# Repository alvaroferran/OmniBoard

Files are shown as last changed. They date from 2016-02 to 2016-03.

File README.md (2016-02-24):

# OmniBoard

<p align="center">
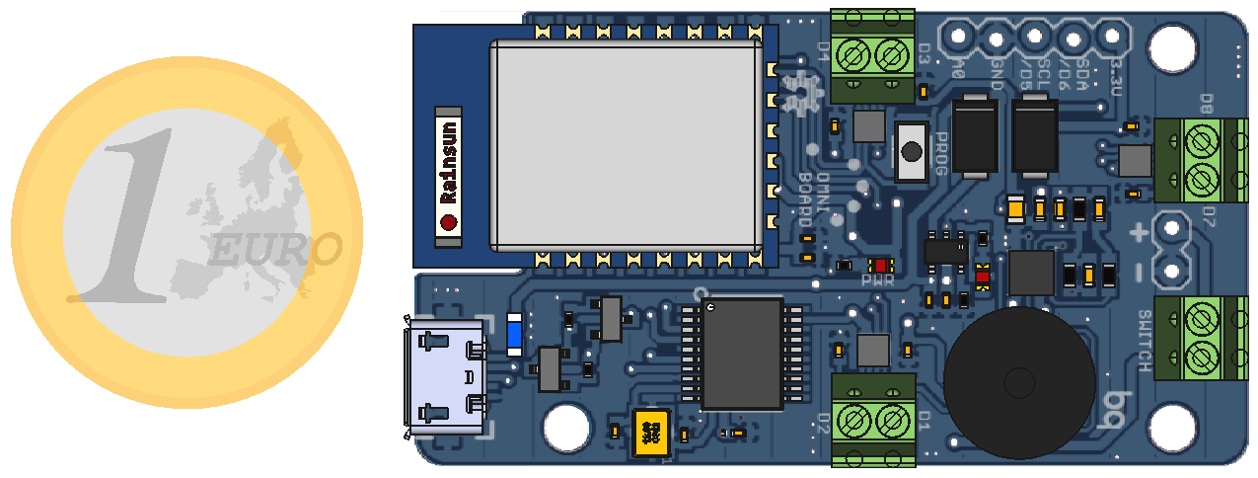
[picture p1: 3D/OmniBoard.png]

</p>

<br>

OmniBoard is a robotics controller board based on the ESP-12 module used to control up to three DC motors over wifi. It includes a 1S LiPo battery charger, a 3.5A boost circuit to ramp the voltage up to 5V for the motors and a hardware buzzer-based battery level indicator.

This board has been used to drive  <a href="https://github.com/bqlabs/miniloki">miniloki</a>:

<br>
This project is licensed under Creative Commons Attribution-ShareAlike 4.0 International (CC BY-SA 4.0)

<p align="center">

</p>

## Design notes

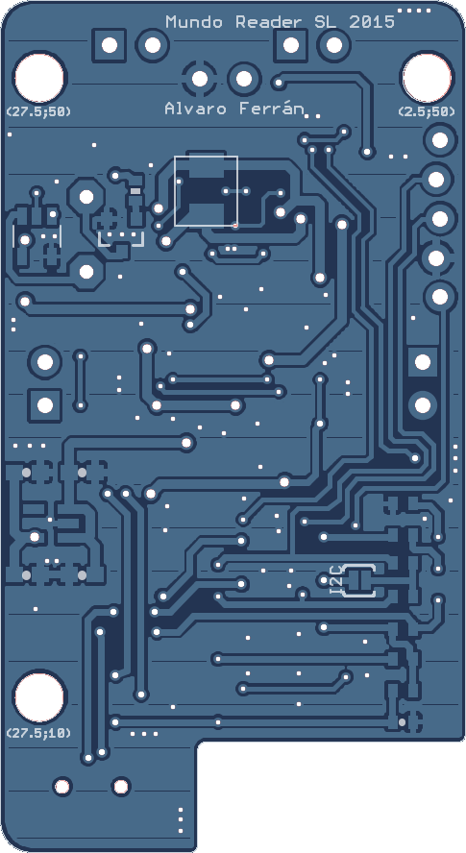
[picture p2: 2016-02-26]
Eagle/Silkscreen/Silkscreen2-Bottom.png

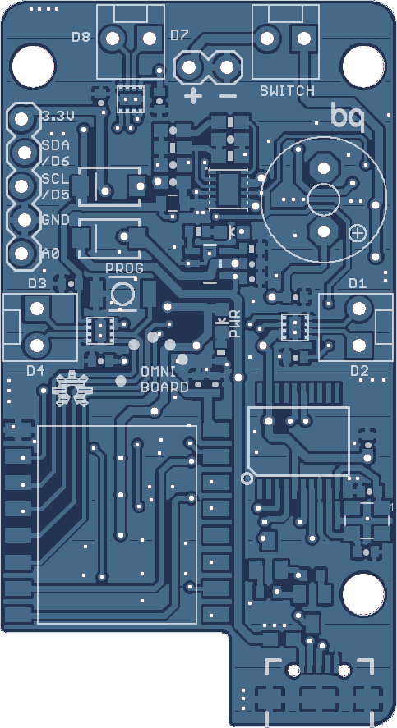
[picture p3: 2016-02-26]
Eagle/Silkscreen/Silkscreen1-Top.png

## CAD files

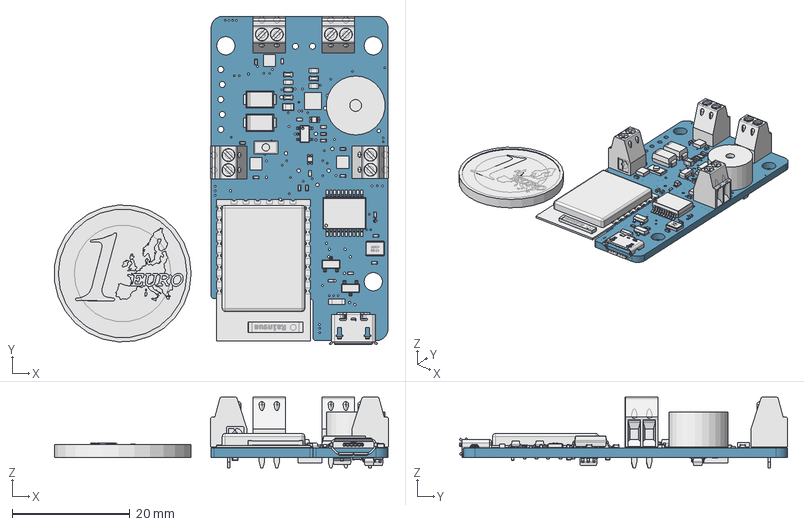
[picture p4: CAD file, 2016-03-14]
3D/OmniBoard.fcstd
56.6 x 55.7 x 12.0 mm
Board
R1
R2
R3
R4
R5
R9
R10
R11
R12
C2
C3
C5
C11
C10
C6
C18
C22
C19
C23
C17
C21
C14
C20
F1
JP2
Q1
U2
X1
IC1
U3
U4
C13
C15
C12
C16
C1
C4
C8
C7
JP1
JP3
JP4
JP7
U6
U7
U5
Q2
Q3
R14
R15
R13
R16
LED1
LED2
D2
D1
Q4
SG1
SW1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

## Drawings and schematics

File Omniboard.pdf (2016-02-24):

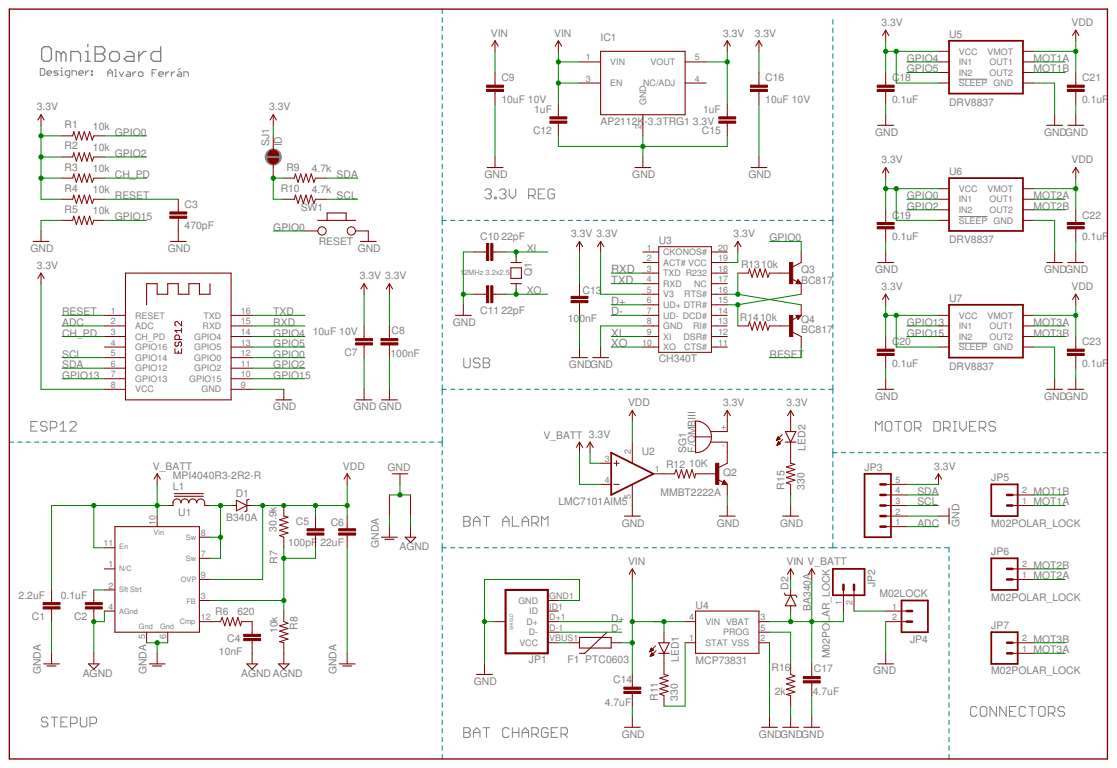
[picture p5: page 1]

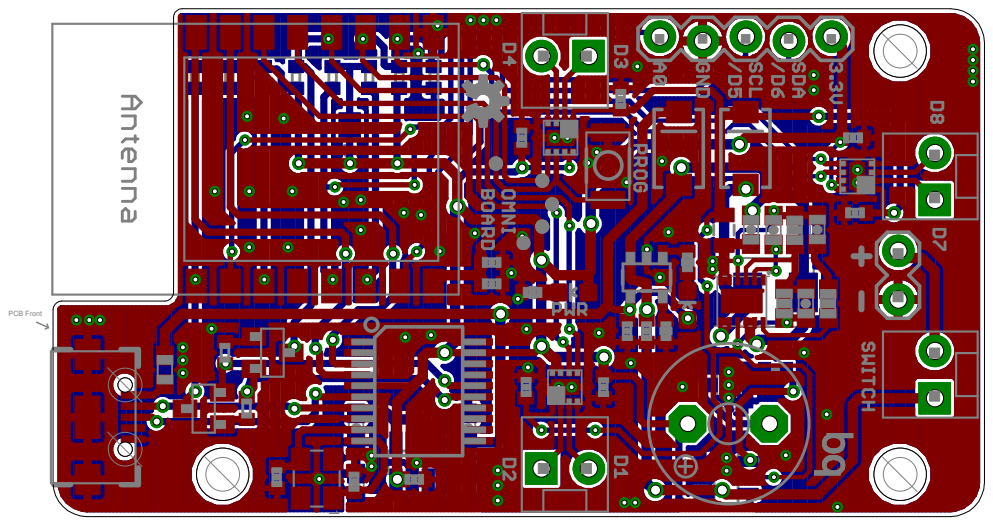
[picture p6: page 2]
PCB Front

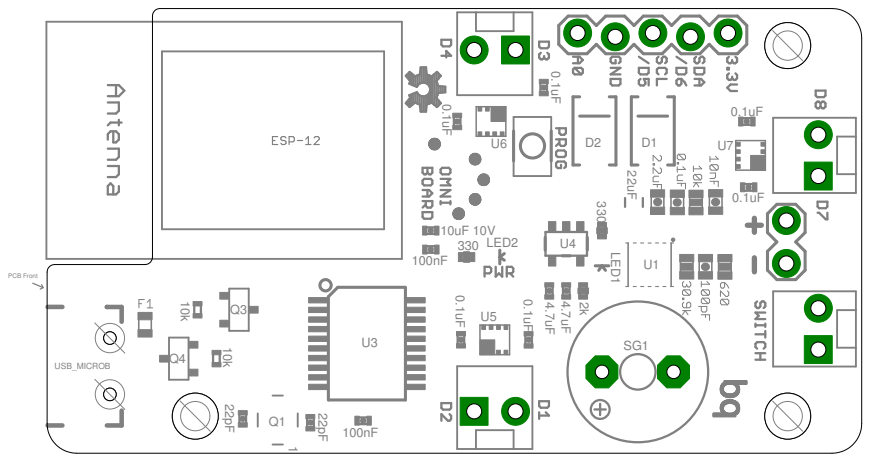
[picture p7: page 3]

U2

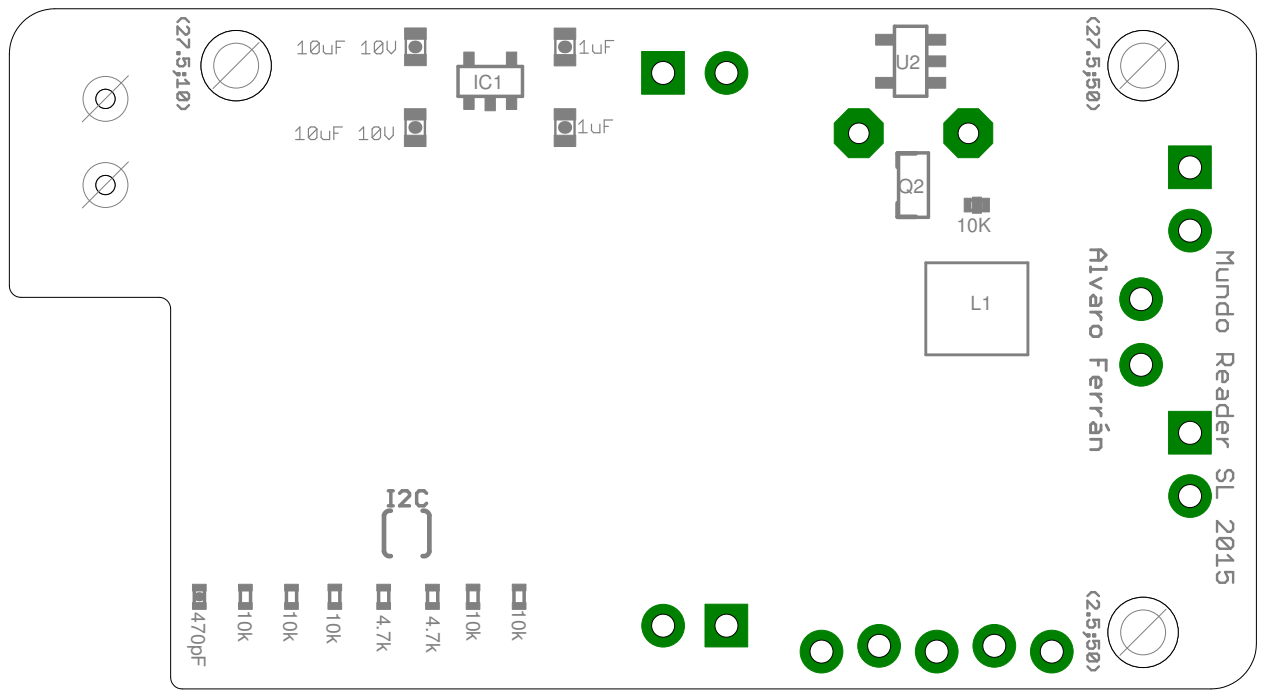
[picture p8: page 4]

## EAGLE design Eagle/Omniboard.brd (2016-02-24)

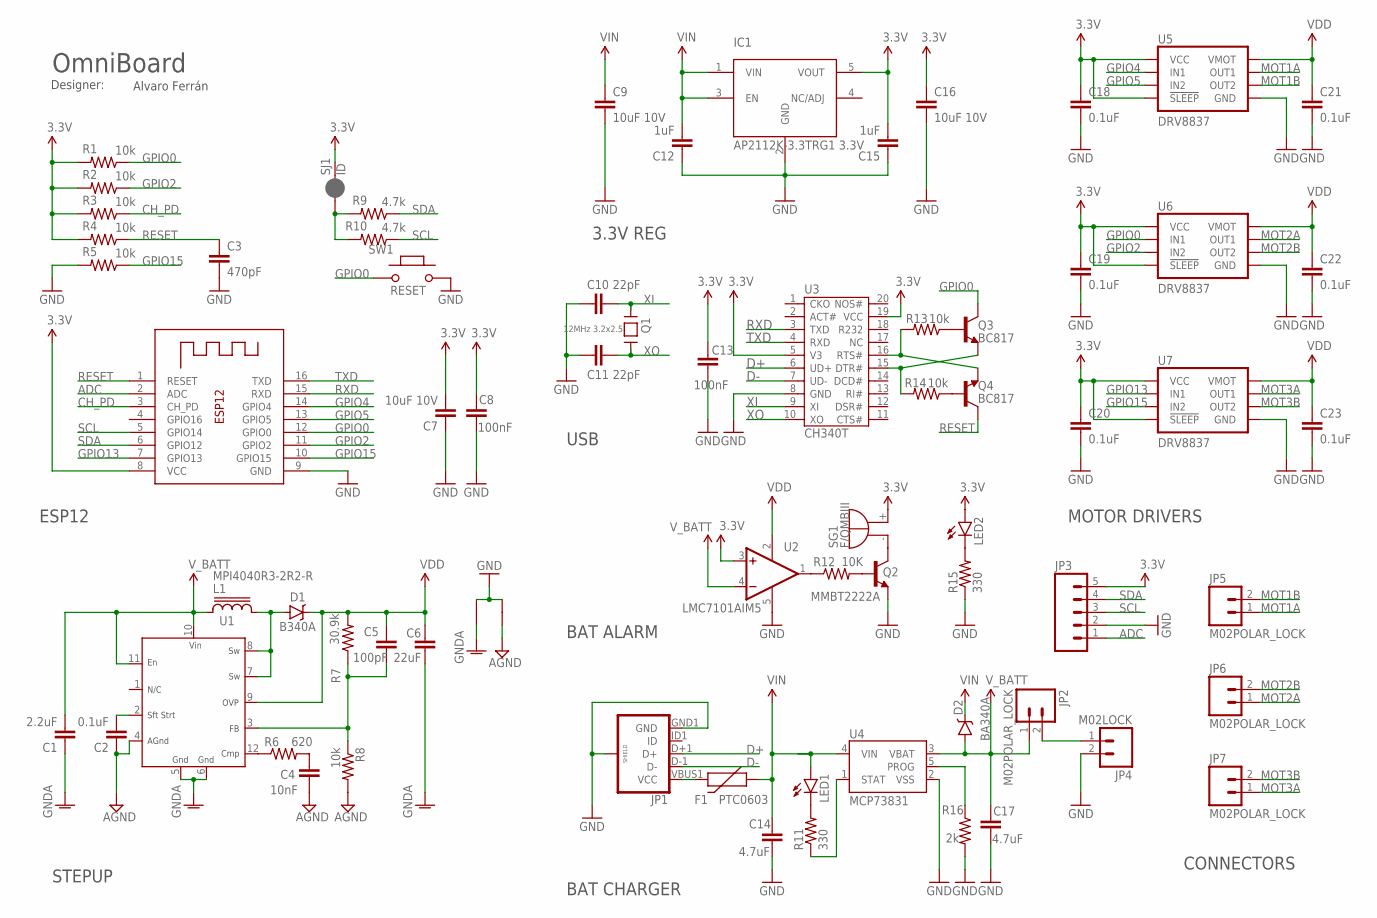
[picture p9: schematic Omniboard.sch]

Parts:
C1: 2.2uF; 0603-CAP
C2: 0.1uF; 0603-CAP
C3: 470pF; 0402-CAP
C4: 10nF; 0603-CAP
C5: 100pF; 0603-CAP
C6: 22uF; 0805
C7: 10uF 10V; 0402-CAP
C8, C13: 100nF; 0402-CAP
C9, C16: 10uF 10V; 0603-CAP
C10, C11: 22pF; 0402-CAP
C12, C15: 1uF; 0603-CAP
C14, C17: 4.7uF; 0402-CAP
C18, C19, C20, C21, C22, C23: 0.1uF; 0402-CAP
D1: B340A; SMA-DIODE
D2: BA340A; SMA-DIODE
F1: PTC0603; 0603
GND10, GND13: VIRTUAL_GND; STARGND
IC1: AP2112K-3.3TRG1 3.3V; SOT23-5
JP1: USB_MICROB; USB-B-MICRO-SMD_V03
JP2, JP5, JP6, JP7: M02POLAR_LOCK; MOLEX-1X2_LOCK
JP3: M05LOCK; 1X05_LOCK
JP4: M02LOCK; 1X02_LOCK
L1: MPI4040R3-2R2-R
LED1, LED2: LED0603; LED-0603
Q1: 12MHz 3.2x2.5; CRYSTAL_3.2X2.5
Q2: MMBT2222A; SOT23-3
Q3, Q4: BC817; SOT23-BEC
R1, R2, R3, R4, R5, R13, R14: 10k; R0402
R6: 620; 0603-RES
R7: 30.9k; 0603-RES
R8: 10k; 0603-RES
R9, R10: 4.7k; R0402
R11, R15: 330; 0402-RES
R12: 10K; 0402-RES
R16: 2k; 0402-RES
SG1: F/QMBIII
SJ1: ID; PAD-JUMPER-2-NC_BY_PASTE_YES_SILK
SW1: RESET; 157SW
U1: MIC2253; MLF12_3.0MM_X_3.0MM
U2: LMC7101AIM5; SOT23-5
U3: CH340T; SSOP20
U4: MCP73831; SOT23-5
U5, U6, U7: DRV8837; DSG
X1: ESP-12

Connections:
3.3V: C7.2, C8.1, C13.2, C15.2, C16.1, C18.1, C19.1, C20.1, IC1.5 (VOUT), JP3.5, LED2.A, R1.2, R2.2, R3.2, R4.2, SG1.+ (-), SJ1.2, U2.3 (+IN), U3.5 (V3), U3.19 (VCC), U5.7 (!SLEEP), U5.8 (VCC), U6.7 (!SLEEP), U6.8 (VCC), U7.7 (!SLEEP), U7.8 (VCC), X1.8 (VCC)
ADC: JP3.1, X1.2 (ADC)
AGND: C2.1, C4.1, GND13.P$1, R8.2, U1.4 (AGND)
CH_PD: R3.1, X1.3 (CH_PD)
D+: JP1.D+1 (D+), U3.6 (UD+)
D-: JP1.D-1 (D-), U3.7 (UD-)
GND: C3.2, C7.1, C8.2, C9.2, C10.1, C11.1, C12.1, C13.1, C14.2, C15.1, C16.2, C17.2, C18.2, C19.2, C20.2, C21.2, C22.2, C23.2, GND10.P$2, GND13.P$2, IC1.2 (GND), JP1.GND1 (GND), JP1.SHIELD1 (SHIELD), JP1.SHIELD2 (SHIELD), JP1.SHIELD3 (SHIELD), JP3.2, JP4.2, Q2.2 (E), R5.2, R15.1, R16.2, SW1.2, U2.5 (V-), U3.8 (GND), U4.2 (VSS), U5.4 (GND), U5.PAD (GND), U6.4 (GND), U6.PAD (GND), U7.4 (GND), U7.PAD (GND), X1.9 (GND)
GPIO0: Q3.C, R1.1, SW1.1, U6.6 (IN1), X1.12 (GPIO0)
GPIO2: R2.1, U6.5 (IN2), X1.11 (GPIO2)
GPIO4: U5.6 (IN1), X1.14 (GPIO4)
GPIO5: U5.5 (IN2), X1.13 (GPIO5)
GPIO13: U7.6 (IN1), X1.7 (GPIO13)
GPIO15: R5.1, U7.5 (IN2), X1.10 (GPIO15)
MOT1A: JP5.1, U5.2 (OUT1)
MOT1B: JP5.2, U5.3 (OUT2)
MOT2A: JP6.1, U6.2 (OUT1)
MOT2B: JP6.2, U6.3 (OUT2)
MOT3A: JP7.1, U7.2 (OUT1)
MOT3B: JP7.2, U7.3 (OUT2)
unnamed: R9.2, R10.2, SJ1.1
unnamed: Q3.E, R14.2, U3.15 (DTR#)
unnamed: C4.2, R6.2
unnamed: C2.2, U1.2 (SS)
unnamed: LED1.C, R11.2
unnamed: Q3.B, R13.1
unnamed: Q4.B, R14.1
unnamed: Q2.1 (B), R12.2
unnamed: Q2.3 (C), SG1.- (+)
unnamed: Q4.E, R13.2, U3.16 (RTS#)
unnamed: R16.1, U4.5 (PROG)
unnamed: D1.A, L1.P$2 (2), U1.7 (SW), U1.8 (SW)
unnamed: R11.1, U4.1 (STAT)
unnamed: F1.2, JP1.VBUS1 (VCC)
unnamed: LED2.C, R15.2
unnamed: R6.1, U1.12 (CMP)
unnamed: R12.1, U2.1 (OUT)
unnamed: C5.1, R7.1, R8.1, U1.3 (FB)
PGND: C1.1, C6.1, GND10.P$1, U1.5 (GND), U1.6 (GND)
RESET: C3.1, Q4.C, R4.1, X1.1 (RESET)
RXD: U3.3 (TXD), X1.15 (RXD)
SCL: JP3.3, R10.1, X1.5 (GPIO14)
SDA: JP3.4, R9.1, X1.6 (GPIO12)
TXD: U3.4 (RXD), X1.16 (TXD)
VBAT: JP2.2, JP4.1
VDD: C5.2, C6.2, C21.1, C22.1, C23.1, D1.C, R7.2, U1.9 (OVP), U2.2 (V+), U5.1 (VMOT), U6.1 (VMOT), U7.1 (VMOT)
VIN: C9.1, C12.2, C14.1, D2.C, F1.1, IC1.1 (VIN), IC1.3 (EN), LED1.A, U4.4 (VIN)
V_BATT: C1.2, C17.1, D2.A, JP2.1, L1.P$1 (1), U1.10 (VIN), U1.11 (EN), U2.4 (-IN), U4.3 (VBAT)
XI: C10.2, Q1.3, U3.9 (XI)
XO: C11.2, Q1.1, U3.10 (XO)

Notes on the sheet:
USB
OmniBoard
Designer:
Alvaro Ferrán
3.3V REG
ESP12
MOTOR DRIVERS
BAT ALARM
CONNECTORS
BAT CHARGER
STEPUP

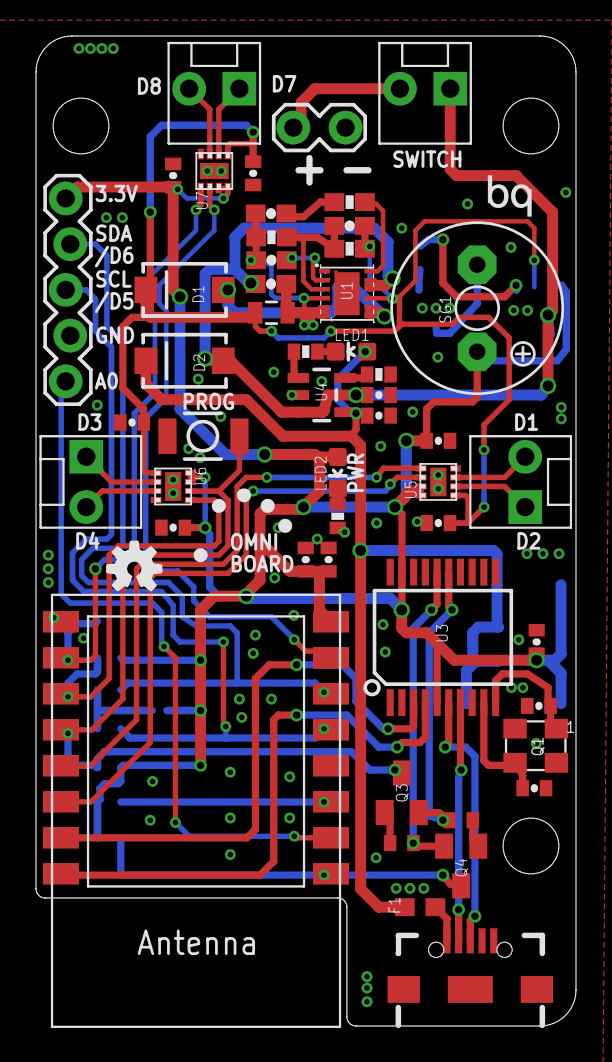
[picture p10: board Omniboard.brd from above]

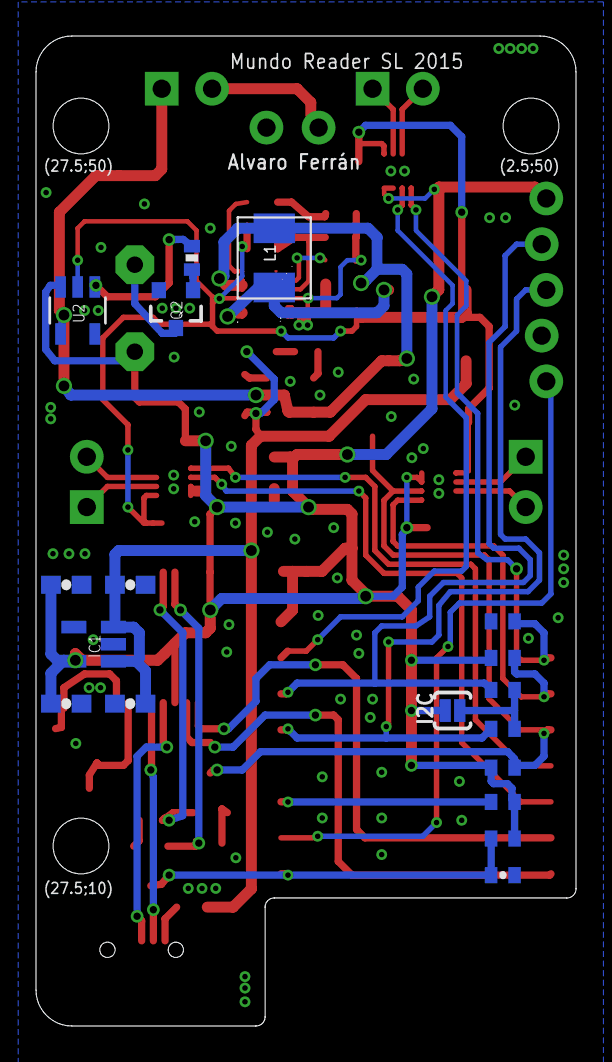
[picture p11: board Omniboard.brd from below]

Board: 2 copper layers, 30.0 x 55.0 mm, 73 parts (18 on the bottom side), 49 nets.

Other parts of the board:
U$1: OSHW-LOGO-S
U$3: BQ_LOGO_SMALL_2
U$4: BQ_LOGO_SMALL_1

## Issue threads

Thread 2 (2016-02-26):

Comparator is not working

alvaroferran, 2016-02-26:
Add 1/2 voltage dividers to each comparator pin so the buzzer trips at half the voltage so the board remains powered

Closed 2017-08-16.

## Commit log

2015-11-30 Board added
    [Omniboard.brd, Omniboard.fcstd, Omniboard.sch]
2015-12-22 Changed to 1S lipo, button added, bugs fixed
    [Omniboard.brd, Omniboard.fcstd, Omniboard.sch]
2016-02-24 Project updated
    [OmniBoard.fcstd, Omniboard.brd, Omniboard.sch]
2016-02-26 Doc added
    [OmniBoard.fcstd]
2016-03-14 json added
    [OmniBoard.fcstd]

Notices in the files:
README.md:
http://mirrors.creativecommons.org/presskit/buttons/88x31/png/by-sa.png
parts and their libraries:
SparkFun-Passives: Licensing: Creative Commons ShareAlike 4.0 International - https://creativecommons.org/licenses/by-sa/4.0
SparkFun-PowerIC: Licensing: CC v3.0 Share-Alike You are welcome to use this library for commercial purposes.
